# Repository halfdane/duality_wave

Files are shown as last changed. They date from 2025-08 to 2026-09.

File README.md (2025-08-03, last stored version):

# Wave Keyboard Case Design

This directory contains the Build123d project for designing the Wave keyboard case.

## Structure
- `env_manager.sh`: Script to manage the virtual environment
- `requirements.txt`: Python dependencies
- `notebook.ipynb`: Jupyter notebook for iterative design
- `models/`: Directory containing reusable models
  - `switch.py`: Kailh Choc switch model
  - `xiao.py`: Seeed XIAO BLE board model
- `prototype.py`: A simple prototype model with a single switch and XIAO board

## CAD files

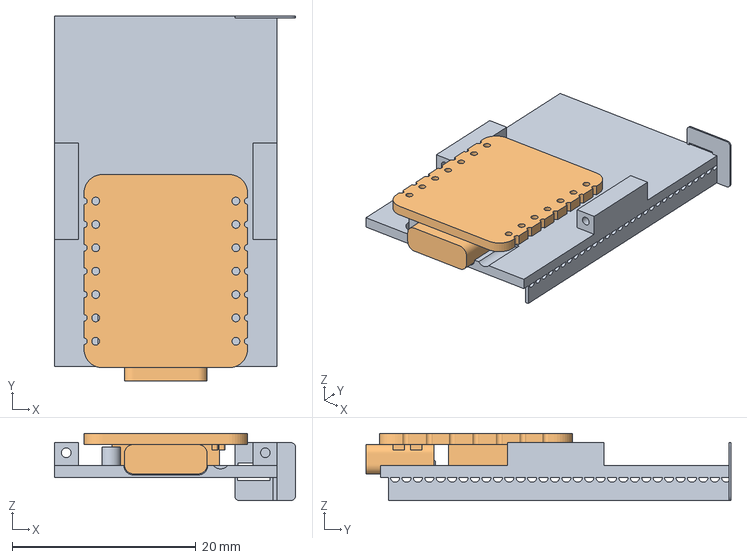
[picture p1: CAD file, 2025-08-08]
freecad/xiao_fit_2.FCStd
26.2 x 39.6 x 7.30 mm
Bottom
SeeedXiao-01

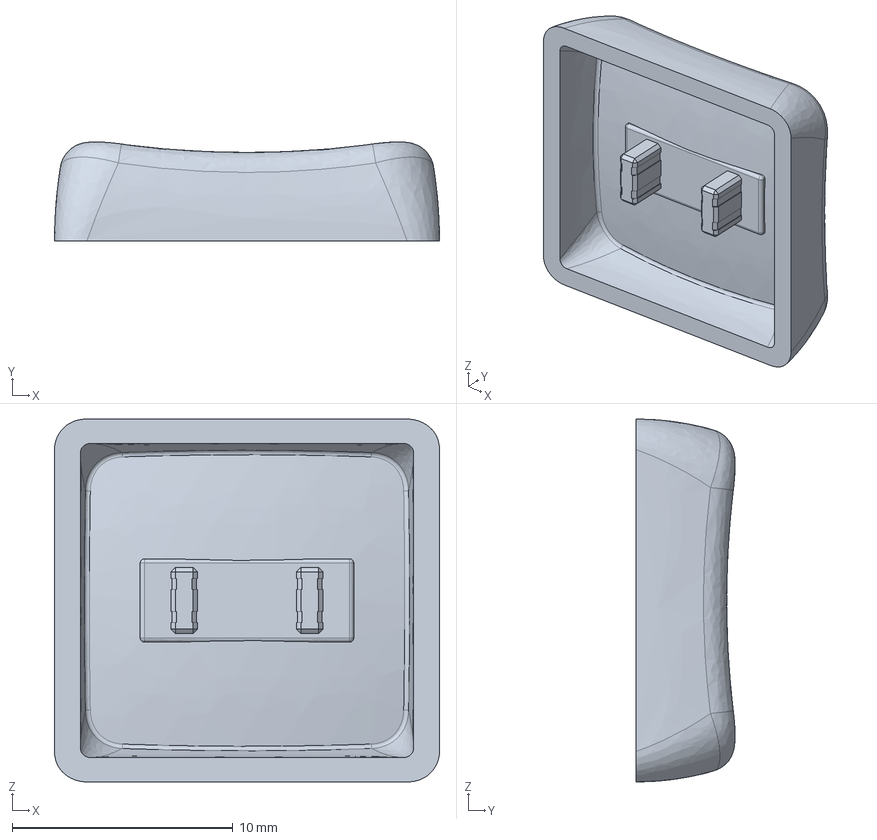
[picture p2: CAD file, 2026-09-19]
models/hattara.step
17.5 x 4.50 x 16.5 mm

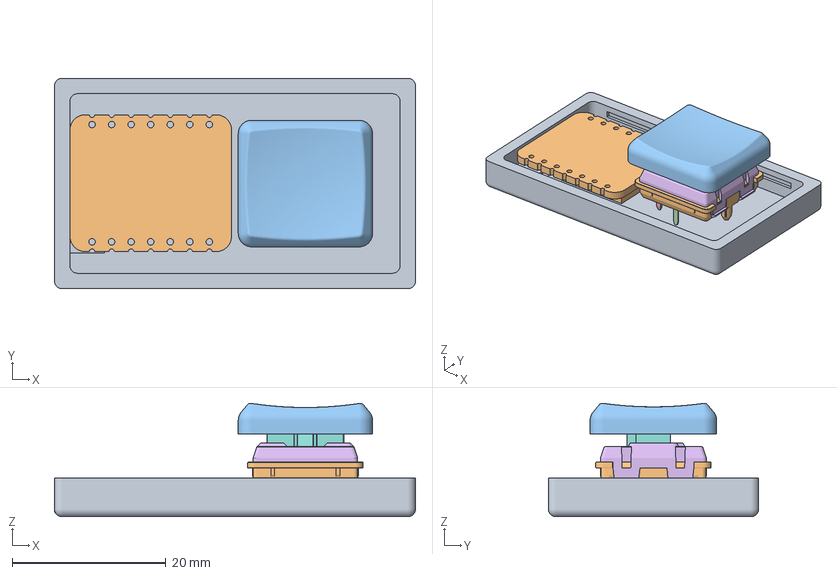
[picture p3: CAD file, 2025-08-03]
freecad/xiao_fit.FCStd
46.9 x 27.3 x 14.7 mm
BodyCase
bottom_stabilizer
contact
pin1
pin2
top_stabilizer
stabilizer
stem_stabilizer
shrunken_spring
SeeedXiao-01
MBK_Keycap_-_1u

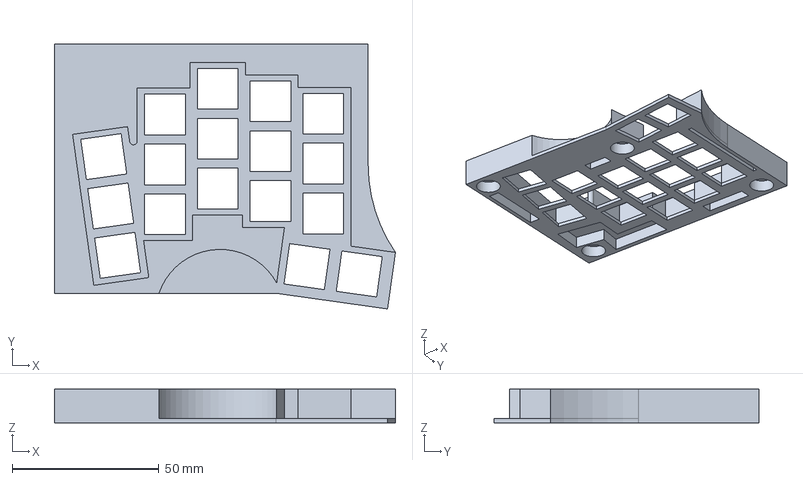
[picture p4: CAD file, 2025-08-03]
freecad/wave_case.FCStd
116.3 x 90.3 x 11.5 mm

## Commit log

2025-07-17 initial fitting test print
    [BodyCase (0.01).stl, BodyCase (0.02).stl, BodyLid (0.01).stl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]
2025-08-03 more experiments with freecad
    [wave_case.FCStd, xiao_fit.FCStd, xiao_fit_2.FCStd]
2025-08-03 first attempts with build123d
    [Kailh_PG1353.STEP, XIAO-nRF52840 v15.step, red.step]
2025-08-08 getting the hang of build123d
    [Kailh_PG1353.STEP, XIAO-nRF52840 v15.step, red.step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]
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2025-09-01 adjust size of clipper-pin and reposition keys so as to not interfere with the walls
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2025-09-14 add electric pins to switches and create left and right parts of board
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2025-09-24 make case slimmer by recessing switch posts into bottom-plate, along with necessary adjustments. Introduce powerswitch
2025-09-27 get rid of ribs on bottom plate and refactor the reset lever
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2025-10-03 using a nail as a pin, which required a bit of shuffling
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2025-10-04 make outline and key positions parameterizable so other switches and caps can be supported as well
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2025-11-07 put switch clearance not into switch but when cutting out the hole
2025-11-08 introduce parent class for case dimensions as well as a positioning of space invaders
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2026-08-20 bootstrap: adopt build123d/uv tooling scaffold (squashed from duality_wave e457cd3..cef9cb4)
    [BodyCase (0.01).stl, BodyCase (0.02).stl, BodyLid (0.01).stl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]
2026-08-21 fix: adjust magnet positioning and extrude logic for improved alignment
2026-09-05 fix: update battery recess dimensions for improved fit
2026-09-19 fix: adjust magnet position calculation and update keywell outline clearance scale for improved fit
2026-09-19 fix: update magnet recess calculation and adjust extrusion depth for improved design accuracy
2026-09-19 fix: update switch plate hole size for improved fit and remove outdated comment
2026-09-19 feat: add hattara key cap
    [hattara.step]
2026-09-19 fix: add bottom plate cutouts for choc contact pins
2026-09-20 fix: add right side offset and mirror accessory handling for dual-side case creation
2026-09-27 fix: integrate part packing functionality and update main execution flow
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2026-10-17 feat: ✨ don't mirror switch cutouts - can't mirror switches irl; create a recession for diodes; improve positioning of screws
2026-11-04 refactor: replace insert_profile with a PrintProfile of per-feature fit constants
    CaseDimensions now carries a print_profile. Clearances are split per feature
    (plate perimeter, switch, magnet, weight, battery); defaults reproduce the
    previous geometry. HeatSetInsert takes the pilot radius directly. Also drops a
    stray 'from sympy import shape' from snap_fit.py.
2026-11-04 fix: make the inner outline corner fillets deterministic
    create_inner_outline filleted stale vertices in the order OCCT returned them.
    That order changes between runs, so the corners of the cavity, keyplate and
    bottom plate were rounded differently from one run to the next (inner outline
    area varied by about 0.2 mm2 and the plates could end up with a sharp corner
    where the cavity had a rounded one). Corners are now filleted one at a time in
    a fixed order, re-reading the vertices after each fillet.
2026-11-04 feat: counter elephant foot with chamfers and add optional switch corner relief
    The keyplate and bottom plate get a larger chamfer (plate_bed_chamfer) on the
    face that sits on the print bed, and the switch cutouts and magnet recesses get
    a mouth chamfer where they open towards the bed. The cutters live in
    models/features.py so calibration coupons can reuse them. switch_corner_relief
    (default off) adds relief circles in the corners of the switch cutouts.
2026-11-04 fix: show heat-set inserts flush with the keywell face
    The inserts are pressed in until they sit flush with the face at z=0, not
    against the end of the pilot hole. Only the visual accessory changes.
2026-11-04 refactor: rename plate_lead_chamfer to plate_edge_chamfer
    The keyplate is printed with the face that enters the cavity first on the bed,
    so 'lead' was misleading. The setting is the chamfer on the plate edges that do
    not face the print bed.
2026-11-04 feat: add fit calibration coupons and remove the insert coupon
    coupons.py builds four coupons in their real print orientation from the same
    cutters and PrintProfile as the case: switch cutouts (size x corner relief),
    plate clearance in a keywell-like cavity, magnet recesses and insert pilots,
    and weight/battery pockets. 'task coupons' exports them as one print plate.
    Also adds a 'task test' entry point.
2026-11-04 test: give the footprint test the dims attribute add_switch_post_cutouts needs
    The test builds WaveCase.__new__ without running __init__, so it broke when the
    cutout code started reading self.dims.bottom_plate_z.
2026-11-04 fix: make WaveCase work with debug=False
    Pin was only created inside create_accessories, which returns early without
    debug, and the accessory dictionaries were built unconditionally. Pin is now
    created in __init__ and the accessory models and viewer pushes only happen with
    debug=True. The generated parts are identical either way.
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2026-11-04 feat: relieve switch cutout corners by 0.3 mm by default
    The coupon now sweeps relief radii 0, 0.2 and 0.4 mm. The feature tests build
    their profiles without relief explicitly.
2026-11-04 refactor: remove the retaining pin
    The pin only secured the parts while the case relied on snap fits. The screws
    hold the stack now, so the pin holes in all three parts, the keyplate pocket,
    the boss on the bottom plate and the Pin model are gone. The bottom plate is
    now 3.0 mm tall instead of 5.9 mm because of the missing boss.
2026-11-04 refactor: drop the edge reordering of the outline sketches
    reorient_edges rebuilt every wire with its edges sorted by polar angle around
    the vertex average. Without it the keywell, keyplate and bottom parts of both
    layouts come out identical (volume, bounding box, face count, validity), and
    the polar sort is only valid for shapes that are star-shaped around that
    point. Also removes the centroid helper.
2026-11-04 refactor: replace the bundled Hattara keycap model with a plain stand-in
    models/hattara.step was a third-party file (TAPR OHL). The switch model now uses
    a rounded block with the same footprint and the same height (top at z=8.02) for
    the preview, so the case geometry does not change. The real caps are linked in
    the README.
2026-11-04 feat: render README images with Blender
    render.py exports the assembled case as meshes, render_blender.py renders a
    hero view, a top view, a view of the underside and an exploded view into
    docs/images. 'task render' runs both; Blender comes from 'nix shell'.
2026-11-04 docs: rewrite the README for builders, with renders and credits
    Leads with a render, status, features, bill of materials, printing and assembly.
    Developer notes move to the end. The Hattara keycaps are linked instead of
    bundled.
2026-11-04 fix: remove the weight pocket that swallowed fastener 3
    The 22.9 x 12 mm weight pocket in the top right corner contained the pilot hole
    of the fastener at (70, 65): only a sliver of plastic was left around the
    insert, and the screw tip reached into the weight. The weight only added about
    10 g, so the feature is gone: pocket, accessory, dimensions and the weight
    clearance. Fastener 3 is fully surrounded by material again, and the first
    magnet recess now has a floor like the others. Coupon D keeps only the battery
    pocket for now.
2026-11-04 feat: add xiao_clearance and turn coupon D into a XIAO pocket sweep
    The XIAO pocket of the keyplate moves into models/features.py and takes its
    clearance from the new PrintProfile.xiao_clearance (default unchanged at
    0.02 mm). Coupon D now sweeps that clearance in four pockets with the keyplate's
    window and pocket, next to the battery pocket.
2026-11-04 feat: pack the coupons compactly onto a 180 mm bed
    The coupons used to be laid out in insertion order (218 x 150 mm). The packer now
    tries a few simple orders, turns parts by 90 degrees where that helps and keeps
    the lowest layout: 171 x 126 mm, so the plate also fits 180 mm printers.
2026-11-04 docs: drop the weight from the README and describe the new coupon D
    Also commits the wording changes made by hand to the status, features and
    assembly sections.
2026-11-04 docs: show the XIAO, its silver USB connector and silver magnets in the renders
    Xiao keeps its USB connector as a separate solid and WaveCase keeps the right
    XIAO, so render.py can export the board, the connector and the stacked magnets.
    The Blender script gets a metal material and a gradient environment for
    reflections; the images are re-rendered.
2026-11-04 feat: make thumb cut more organic with s-shaped ease in and out
2026-11-05 refactor: split WaveCase into per-part builders
    - builders/keywell, keyplate, bottom build one blank part each
    - builders/thumb_cut holds the thumb slope cutter and its fillets
    - builders/side runs the same finishing steps for the left and right half
    - builders/accessories builds the viewer-only models without mutating the shared bumper model
    and without requiring magnet positions
    - builders/viewer replaces the debug conditionals. The debug group is pushed last and starts hidden
    - WaveCase keeps the old flat part names as read-only properties
2026-11-05 refactor: use case.left and case.right everywhere and drop the flat part names
    - builders/export writes the STEP files, builders/viewer shows the pushed parts
    - render.py takes the switch placements and the mirror from the built sides
    - WaveCase keeps only its context, no second copy of switch, keys and dims
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2026-11-05 refactor: move the code into the duality_wave package under src/
    - the package has case, layout, coupons, paths, builders, models and cli
    - the entry points run as python -m duality_wave.cli.build, task wraps them
    - paths to the layouts and build/ come from duality_wave.paths
    - the sys.path hacks in the model demos are gone
    - pyproject.toml gets a hatchling build backend, uv installs the package editable
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2026-11-06 fix: build123d 0.13 compatibility
    Wrap Line and offset in BuildLine. 0.13 rejects them in a BuildSketch.
    Build the symbol and the space invader outside Locations. 0.13 applies the
    location of an enclosing Locations to a nested builder, so the engravings
    were cut at twice the position and missed the part.
    Flatten the XIAO connector to the plane of the plate.
    Test for fewer than two points before BuildLine, so no empty BuildLine is made.
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2026-11-06 feat: thumb cut as a loft of one grown zone, chamfer instead of B-spline fillets
    The keywell stage drops from 2.9 s to 0.6 s. The slope shape changes (see the plan, step 5).
    Budgets tightened. docs/baseline/step5.json is the new baseline.
2026-11-06 perf: one boolean per cutter set, one switch hole placed 17 times
    Full build 5.5 s -> 3.2 s, compact 2.1 s -> 1.5 s. Geometry is identical.
    Budgets tightened. docs/baseline/step6.json is the new baseline.
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2026-11-06 Snap the Z levels to whole layers from the bed face (step 7e)
2026-11-06 fix: adjust thumb cut to look nicer
2026-11-07 feat: retune screws, magnets and bumpers; shallower bumper recess with clearance
    Bumper recess is 0.6 mm (3 layers) and snaps to the layer height.
    Bumper cutout gets the general clearance.
    The R-23 wall test measures from the cutout radius.
    Test builds mock the viewer status.
2026-11-07 feat: update bumper clearance in PrintProfile and adjust bumper cutout calculation
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2026-11-08 fix: place engravings on the side, not the top/bottom because these face the printer bed
2026-11-08 refactor: move screw, post and insert fits into PrintProfile; drop component mounts
    Add post_clearance, screw_clearance and screw_head_clearance to PrintProfile.
    The builders add the profile value to the nominal size of the screw and read
    insert_pilot_radius directly, so LowProfileScrew and HeatSetInsert lose their
    mount and constructor arguments.
    Xiao takes the clearance as an argument of the USB cut methods instead of
    storing it. Geometry is unchanged.
2026-11-08 refactor: split the keycap off the switch model
    Choc.split_cap returns the switch body and the keycap. build_switches returns both,
    and Accessories gets a keycaps part next to switches. The collision test of the
    fixtures covers the keycaps as before.
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2026-11-08 fix: widen the post clearance in the bottom plate to 0.2
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2026-11-10 fix: the reset lever arm of the bottom plate survives the STEP export
    The arm head was an offset of the slot outline. STEP files lose the faces that have an offset curve as an edge, so the bottom plate read back as an open shell in the slicer. The head is an ellipse now, and the bump stays inside it.
    R-44 requires that every face of a part can be meshed, R-45 that a STEP file reads back as the same solid.
2026-11-10 feat: the coupons fit the usable area of a Bambu Lab A1 mini on two plates
    arrange() packs into a square bed of 170 mm and raises when the parts do not fit. The plate fit and the wall slabs move to the wiring plate, which leaves two plates: coupons-hardware and coupons-plate-wiring-engraving.
2026-11-10 feat: export-case and export-coupon replace export, and write to build/case and build/coupons
    export-coupon writes every coupon plate. Both commands print the paths they wrote.
2026-11-10 fix: adjust magnet position for pinkie top in CaseDimensions
2026-11-10 fix: adjust battery position calculations and magnet placement for improved alignment
2026-11-10 fix: update battery position calculations and adjust fastener placement for improved alignment
2026-11-10 fix: refine bottom middle magnet position calculation for improved alignment
2026-11-10 feat: add proposal for alignment pin to improve transport pose stability
2026-11-10 fix: update reset button lever dimensions for improved fit and functionality
2026-11-10 fix: improve reset button lever sketch and adjust lever height for preload
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
